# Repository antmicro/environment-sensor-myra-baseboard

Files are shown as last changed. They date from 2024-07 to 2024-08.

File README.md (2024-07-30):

# Environment Sensor MYRA SiP Baseboard
Copyright (c) 2024 [Antmicro](https://www.antmicro.com/)

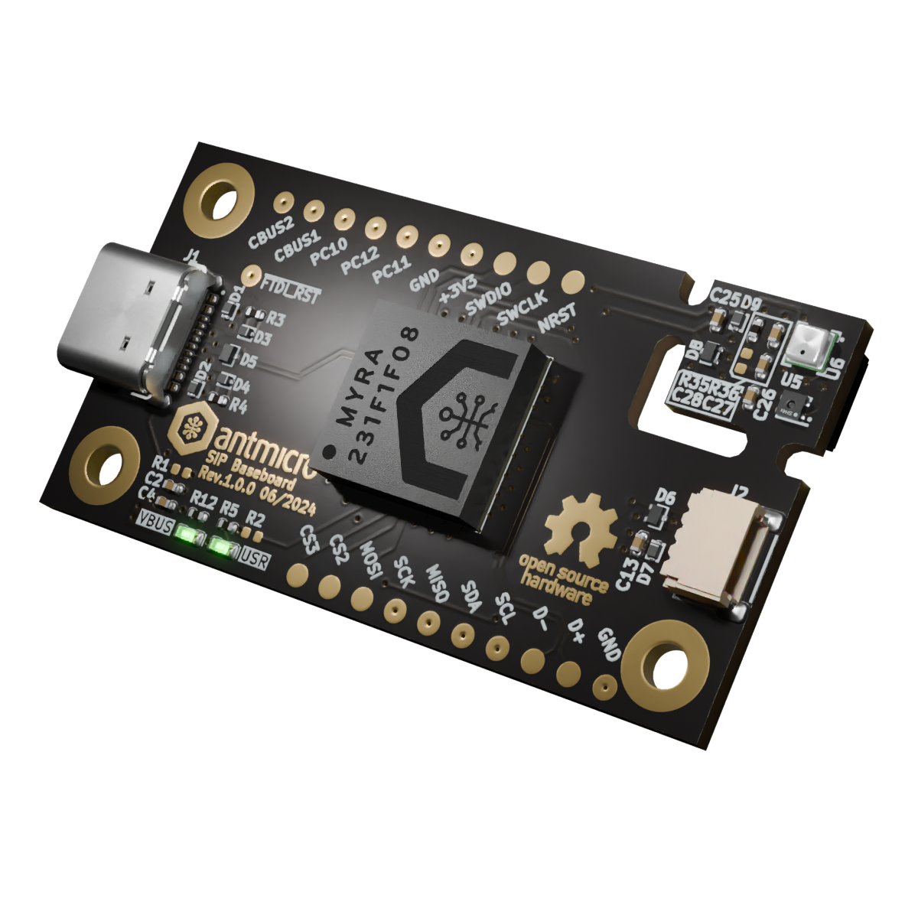
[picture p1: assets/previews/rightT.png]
Visualization


## Overview

This repository contains open hardware design files for Antmicro's Environment Sensor Board variant which includes the [MYRA SiP](https://github.com/antmicro/myra-sip) as well as temperature, pressure and humidity sensors.

The design files were prepared in KiCad 7.

## Key features

* Environment sensor SiP (with STM32G491REI6 MCU, 128kB FRAM, FTDI FT231XQ USB to UART converter)
* 50 mm x 26.5 mm PCB size
* USB-C Connector for data and power
* SHT45 temperature + humidity sensor:
	* typical relative humidity accuracy ±1% RH
	* operating relative humidity range 0-100% RH
	* typical temperature accuracy ±0.1°C
	* operating temperature range -40-125°C
* BME280 temperature + humidity + pressure sensor:
	* typical relative humidity accuracy ±3% RH
	* operating relative humidity range 10-100% RH
	* typical temperature accuracy ±1°C
	* operating temperature range -40-85°C
	* typical pressure accuracy ±1 hPa
	* operating pressure range 300-1100 hPa
* QWIIC Connectors
* RTC battery backup

## Repository structure

The main repository directory contains KiCad PCB project files, a LICENSE, and a README.
The remaining files are stored in the following directories:

* `doc` - contains board schematic
* `assets` - contains visual assets for showcasing this design on [Open Hardware Portal](https://openhardware.antmicro.com/boards/environment-sensor-sip-baseboard/?tab=features&view=top-ortho).

## Licensing
This project is published under the [Apache-2.0](https://github.com/antmicro/environment-sensor-sip-baseboard//blob/main/LICENSE) license.

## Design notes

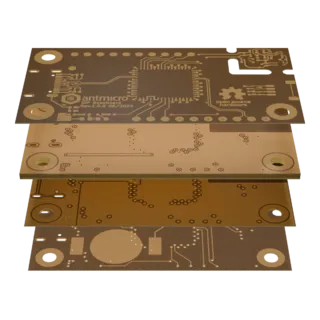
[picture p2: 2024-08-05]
assets/previews/layer1_thumbnail.webp

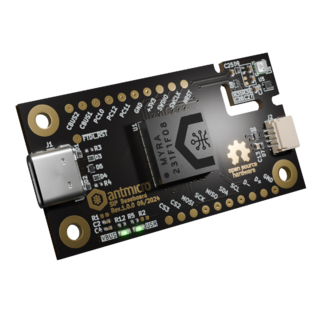
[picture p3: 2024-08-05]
assets/previews/leftT_thumbnail.png

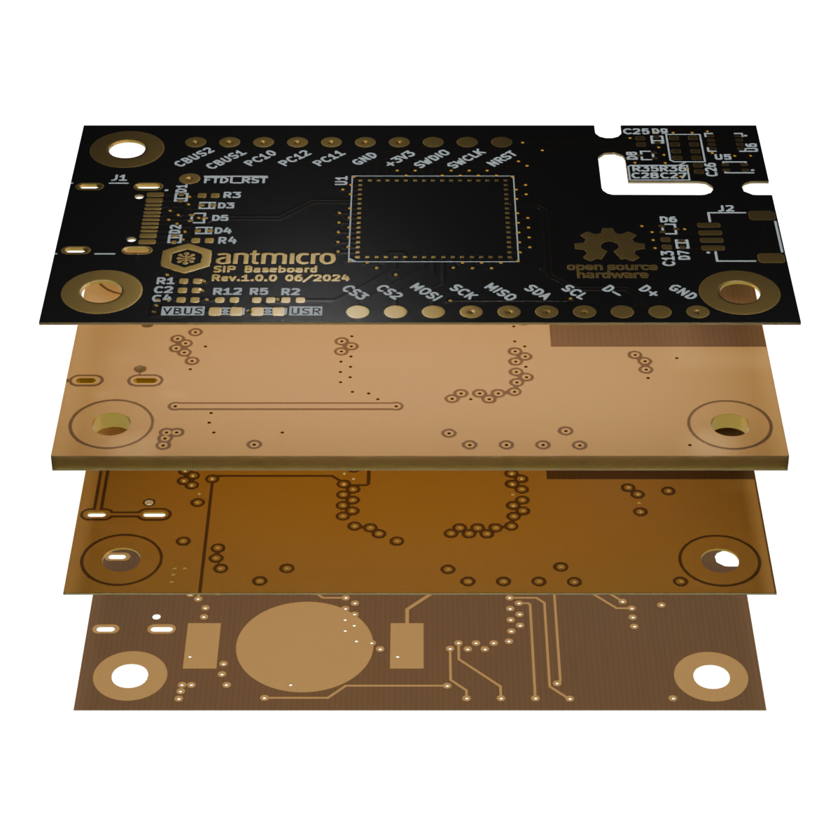
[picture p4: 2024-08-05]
assets/previews/stackup.png

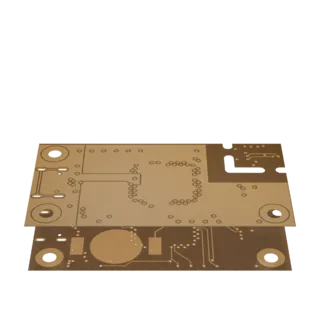
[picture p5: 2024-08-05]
assets/previews/layer3_thumbnail.webp

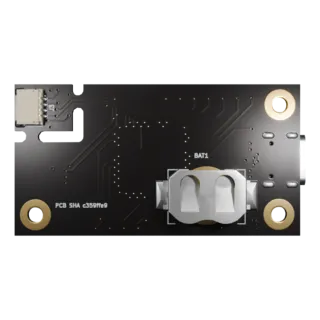
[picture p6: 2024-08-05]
assets/previews/orthoB_thumbnail.webp

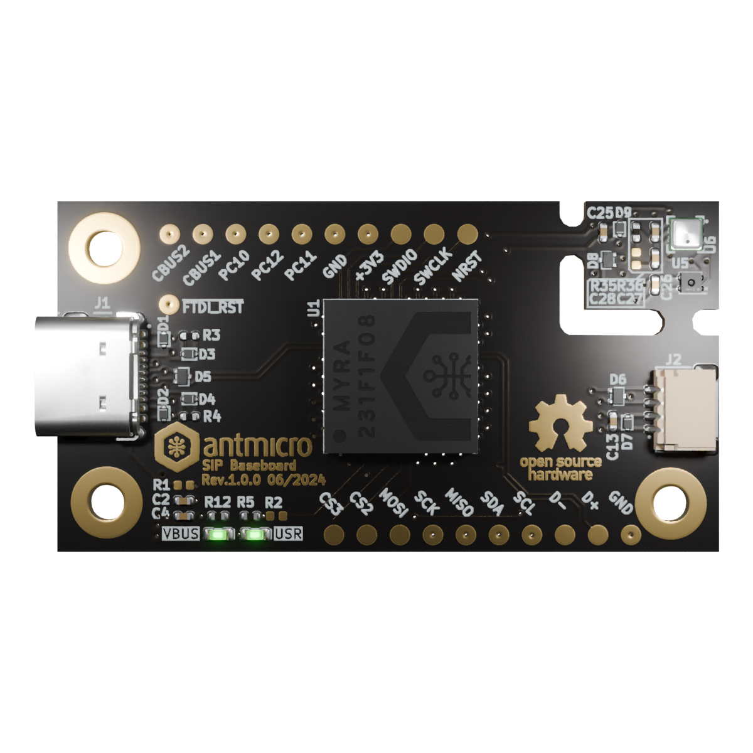
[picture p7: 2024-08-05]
assets/previews/orthoT.png

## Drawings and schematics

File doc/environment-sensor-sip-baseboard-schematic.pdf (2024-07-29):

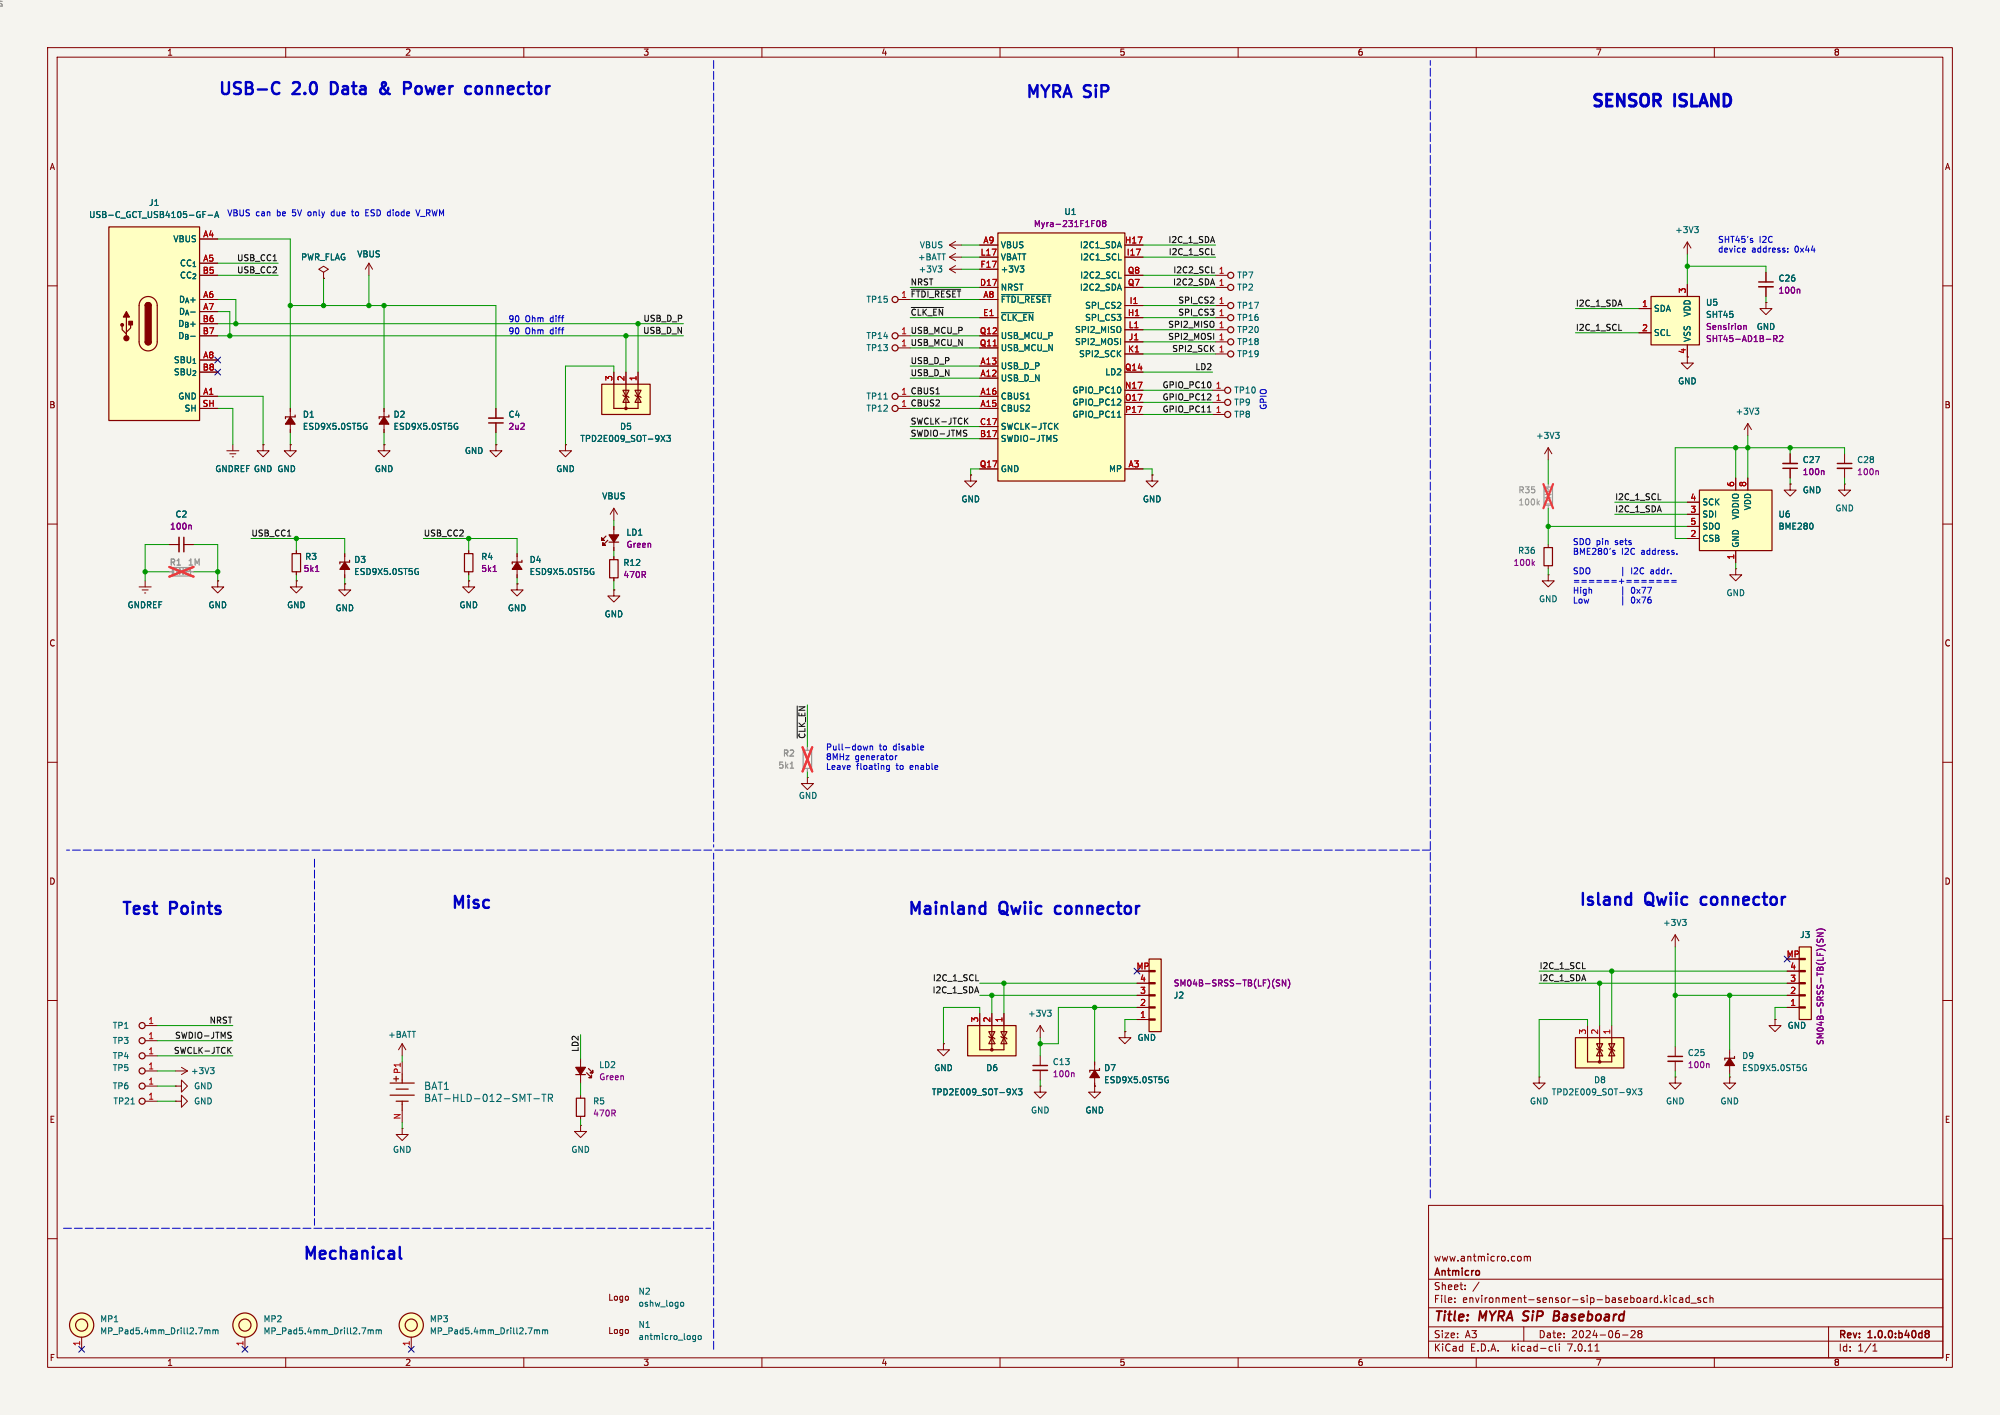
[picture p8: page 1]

VBUS can be 5V only due to ESD diode V_RWM

4 U5SHT45 Sensirion SHT45-AD1B-R2 USB_D_N A12 USB_D_P A13 CBUS2 A15 CBUS1 A16 MP A3 ~{FTDI_RESET} A8 VBUS A9 SWDIO-JTMS B17 SWCLK-JTCK C17 NRST D17 ~{CLK_EN} E1 +3V3 F17 SPI_CS3 H1

J3 SM04B-SRSS-TB(LF)(SN) 1

J2SM04B-SRSS-TB(LF)(SN) C13

File: environment-sensor-sip-baseboard.kicad_sch Sheet: / Antmicro www.antmicro.com

Id: 1/1 Title: MYRA SiP Baseboard

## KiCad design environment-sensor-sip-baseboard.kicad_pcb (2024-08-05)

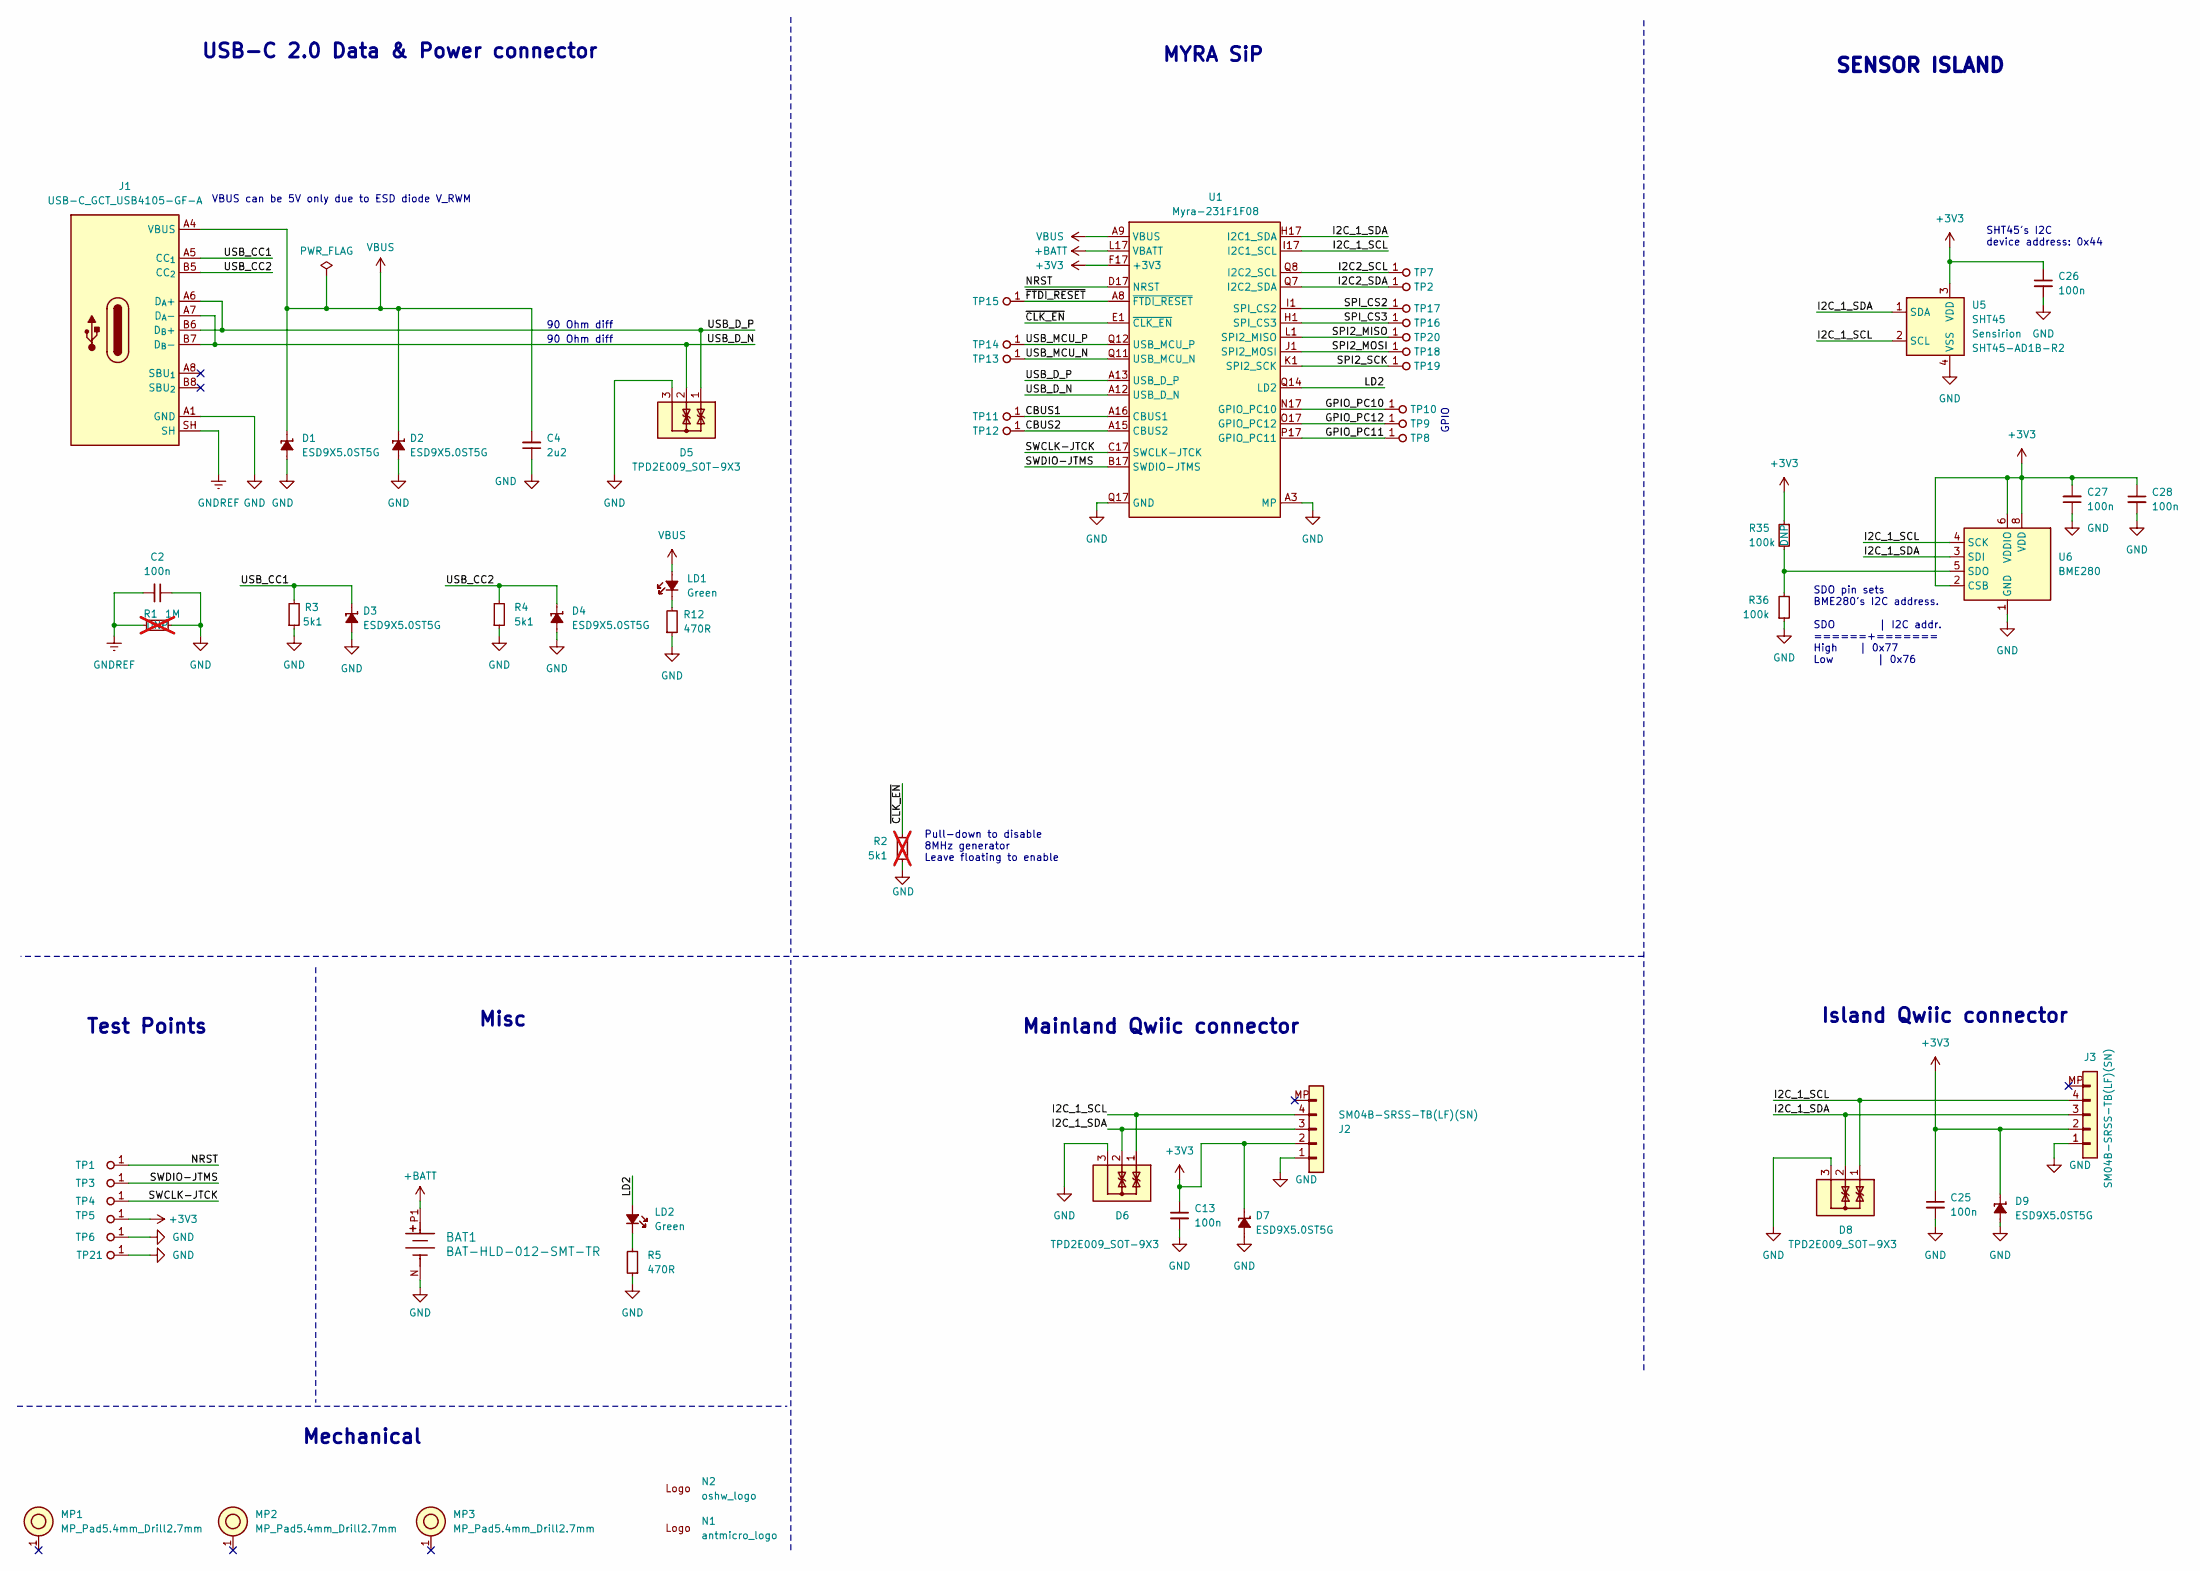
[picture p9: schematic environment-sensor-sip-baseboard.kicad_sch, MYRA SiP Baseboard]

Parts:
BAT1: BAT-HLD-012-SMT-TR; BAT_BAT-HLD-012-SMT-TR; MPN BAT-HLD-012-SMT-TR
C2, C13, C25, C26, C27, C28: C_100n_0402; C_0402_1005Metric; Voltage 50V; MPN GRM155R61H104KE14D
C4: C_2u2_0402; C_0402_1005Metric; MPN C1005X5R1A225K050BC
D1, D2, D3, D4, D7, D9: ESD9X5.0ST5G; SOD-923; MPN ESD9X5.0ST5G
D5, D6, D8: TPD2E009_SOT-9X3; SOT-723; MPN TPD2E009DRTR
J1: USB-C_GCT_USB4105-GF-A; USB-C_Receptacle_GCT_USB4105-GF-A; MPN USB4105-GF-A
J2, J3: JST_SH_1x4_SM04B-SRSS-TB-LF-SN; Conn_JST_SH_1x4_SM04B-SRSS-TB-LF-SN; MPN SM04B-SRSS-TB(LF)(SN)
LD1, LD2: LED_G_0603_KP-1608ZGC; LED_0603_1608Metric_G; MPN KP-1608ZGC
MP1, MP2, MP3: MP_Pad5.4mm_Drill2.7mm
N1: antmicro_logo; antmicro-logo_scaled_12mm
N2: oshw_logo; oshw-logo
R1: R_1M_0402; R_0402_1005Metric; Tolerance 1%; MPN CR0402-FX-1004GLF; not fitted
R2: R_5k1_0402; R_0402_1005Metric; Tolerance 1%; MPN CR0402-FX-5101GLF; not fitted
R3, R4: R_5k1_0402; R_0402_1005Metric; Tolerance 1%; MPN CR0402-FX-5101GLF
R5, R12: R_470R_0402; R_0402_1005Metric; Tolerance 1%; MPN CR0402-FX-4700GLF
R35, R36: R_100k_0402; R_0402_1005Metric; Tolerance 1%; MPN CR0402-FX-1003GLF
TP1, TP2, TP3, TP4, TP5, TP6, TP7, TP8, TP9, TP10, TP11, TP12, TP13, TP14, TP15, TP16, TP17, TP18, TP19, TP20, TP21: TP_1.5mm_SMD; TP_SMD_1.5mm
U1: Myra-231F1F08; LGA-64_11.4x11.4mm_Myra; MPN Myra-231F1F08
U5: SHT45; Sensirion_DFN-4-1.5x1.5x0.5mm_P0.8mm; MPN SHT45-AD1B-R2
U6: BME280; LGA-8_2.5x2.5mm_BME280; MPN BME280

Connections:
+3V3: C13.1, C25.1, C26.1, C27.2, C28.1, D7.1 (C), D9.1 (C), J2.2, J3.2, R35.1, TP5.1, U1.F17 (+3V3), U1.Q6 (+3V3), U5.3 (VDD), U6.2 (CSB), U6.6 (VDDIO), U6.8 (VDD)
+BATT: BAT1.P1, BAT1.P2, U1.L17 (VBATT)
/CBUS1: TP11.1, U1.A16 (CBUS1)
/CBUS2: TP12.1, U1.A15 (CBUS2)
/GPIO_PC10: TP10.1, U1.N17 (GPIO_PC10)
/GPIO_PC11: TP8.1, U1.P17 (GPIO_PC11)
/GPIO_PC12: TP9.1, U1.O17 (GPIO_PC12)
/I2C2_SCL: TP7.1, U1.Q8 (I2C2_SCL)
/I2C2_SDA: TP2.1, U1.Q7 (I2C2_SDA)
/I2C_1_SCL: D6.1, D8.1, J2.4, J3.4, U1.I17 (I2C1_SCL), U5.2 (SCL), U6.4 (SCK)
/I2C_1_SDA: D6.2, D8.2, J2.3, J3.3, U1.H17 (I2C1_SDA), U5.1 (SDA), U6.3 (SDI)
/LD2: LD2.2 (A), U1.Q14 (LD2)
/NRST: TP1.1, U1.D17 (NRST)
/SPI2_MISO: TP20.1, U1.L1 (SPI2_MISO)
/SPI2_MOSI: TP18.1, U1.J1 (SPI2_MOSI)
/SPI2_SCK: TP19.1, U1.K1 (SPI2_SCK)
/SPI_CS2: TP17.1, U1.I1 (SPI_CS2)
/SPI_CS3: TP16.1, U1.H1 (SPI_CS3)
/SWCLK-JTCK: TP4.1, U1.C17 (SWCLK-JTCK)
/SWDIO-JTMS: TP3.1, U1.B17 (SWDIO-JTMS)
/USB_CC1: D3.1 (C), J1.A5 (CC_{1}), R3.2
/USB_CC2: D4.1 (C), J1.B5 (CC_{2}), R4.2
/USB_D_N: D5.2, J1.A7 (D_{A}-), J1.B7 (D_{B}-), U1.A12 (USB_D_N)
/USB_D_P: D5.1, J1.A6 (D_{A}+), J1.B6 (D_{B}+), U1.A13 (USB_D_P)
/USB_MCU_N: TP13.1, U1.Q11 (USB_MCU_N)
/USB_MCU_P: TP14.1, U1.Q12 (USB_MCU_P)
/~CLK_EN: R2.2, U1.E1 (~CLK_EN)
/~FTDI_RESET: TP15.1, U1.A8 (~FTDI_RESET)
GND: BAT1.N, C2.1, C4.1, C13.2, C25.2, C26.2, C27.1, C28.2, D1.2 (A), D2.2 (A), D3.2 (A), D4.2 (A), D5.3, D6.3, D7.2 (A), D8.3, D9.2 (A), J1.A1 (GND), J1.A12 (GND), J1.B1 (GND), J1.B12 (GND), J2.1, J3.1, R1.2, R2.1, R3.1, R4.1, R5.1, R12.1, R36.1, TP6.1, TP21.1, U1.A1 (MP), U1.A2 (MP), U1.A3 (MP), U1.A4 (MP), U1.A5 (MP), U1.A6 (MP), U1.A7 (GND), U1.A11 (GND), U1.A14 (GND), U1.A17 (GND), U1.B1 (MP), U1.C1 (MP), U1.D1 (GND), U1.E17 (GND), U1.F1 (GND), U1.G1 (GND), U1.G17 (GND), U1.J17 (GND), U1.K17 (GND), U1.M1 (GND), U1.M17 (GND), U1.Q5 (GND), U1.Q9 (GND), U1.Q10 (GND), U1.Q13 (GND), U1.Q15 (GND), U1.Q16 (GND), U1.Q17 (GND), U5.4 (VSS), U6.1 (GND), U6.7 (GND)
GNDREF: C2.2, J1.SH, R1.1
unnamed: LD1.1 (C), R12.2
unnamed: LD2.1 (C), R5.2
unnamed: R35.2, R36.2, U6.5 (SDO)
VBUS: C4.2, D1.1 (C), D2.1 (C), J1.A4 (VBUS), J1.A9 (VBUS), J1.B4 (VBUS), J1.B9 (VBUS), LD1.2 (A), U1.A9 (VBUS), U1.A10 (VBUS)

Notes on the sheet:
Island Qwiic connector
MYRA SiP
90 Ohm diff
USB-C 2.0 Data & Power connector
SDO pin sets BME280's I2C address. SDO | I2C addr. ======+======= High | 0x77 Low | 0x76
VBUS can be 5V only due to ESD diode V_RWM
Pull-down to disable 8MHz generator Leave floating to enable
Misc
SENSOR ISLAND
SHT45's I2C device address: 0x44
Mainland Qwiic connector
Test Points
Mechanical
GPIO

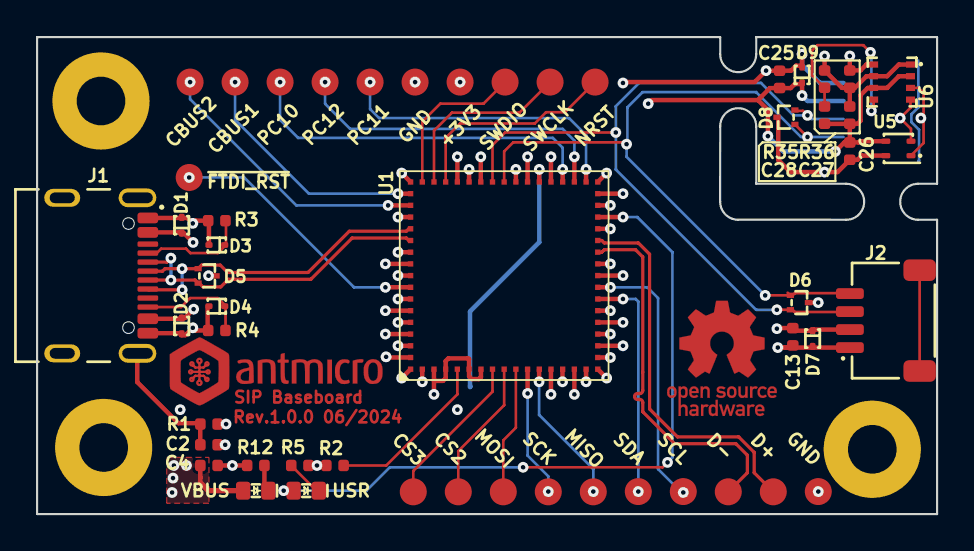
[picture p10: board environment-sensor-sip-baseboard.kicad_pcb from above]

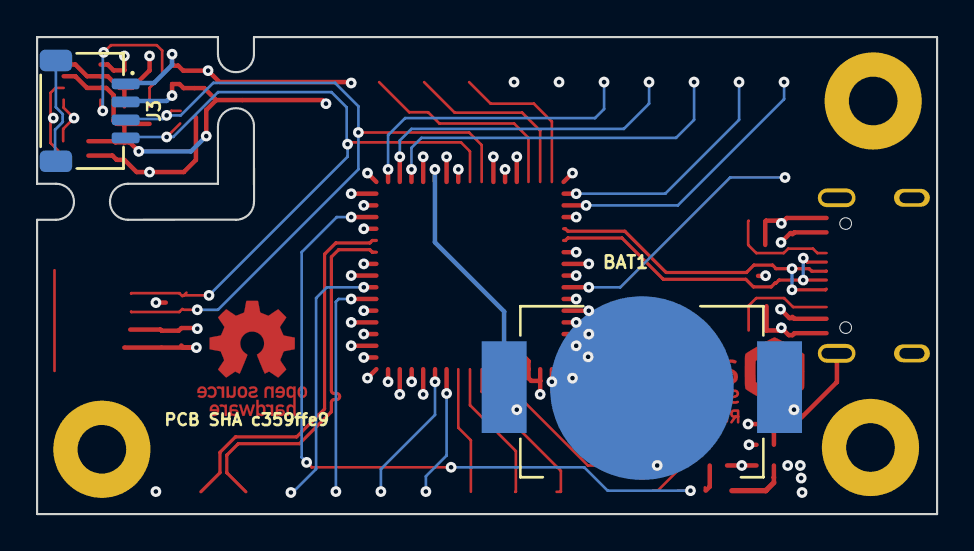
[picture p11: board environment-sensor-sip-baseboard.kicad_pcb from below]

Board: 4 copper layers, 50.0 x 26.5 mm, 59 parts (2 on the bottom side), 34 nets.

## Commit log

2024-06-27 [#61553] Initial commit. Create schematic
    [environment-sensor-sip-baseboard.kicad_sch]
2024-06-27 [#61553] Start PCB placement
    [environment-sensor-sip-baseboard.kicad_pcb]
2024-06-28 [#61553] Route PCB
    [environment-sensor-sip-baseboard.kicad_pcb, environment-sensor-sip-baseboard.kicad_sch]
2024-06-28 [#61553] Improve schematic readability
    [environment-sensor-sip-baseboard.kicad_pcb, environment-sensor-sip-baseboard.kicad_sch]
2024-06-28 [#61553] Update title block
    [environment-sensor-sip-baseboard.kicad_pcb, environment-sensor-sip-baseboard.kicad_sch]
2024-06-28 [#61553] Fix ERC
    [environment-sensor-sip-baseboard.kicad_sch]
2024-06-28 [#61553] Fix logo at PCB
    [environment-sensor-sip-baseboard.kicad_pcb, environment-sensor-sip-baseboard.kicad_sch]
2024-06-28 [#61553] Fill polygons
    [environment-sensor-sip-baseboard.kicad_pcb]
2024-07-12 [#62396] Update components
    [environment-sensor-sip-baseboard.kicad_pcb, environment-sensor-sip-baseboard.kicad_sch]
2024-07-12 [#62396] Update MYRA Description
    [environment-sensor-sip-baseboard.kicad_sch]
2024-07-12 [#62396] Fix ERC and DRC
    [environment-sensor-sip-baseboard.kicad_pcb, environment-sensor-sip-baseboard.kicad_sch]
2024-07-15 [#62396] Update title block
    [environment-sensor-sip-baseboard.kicad_pcb, environment-sensor-sip-baseboard.kicad_sch]
2024-07-16 [#62396] Update SiP
    [environment-sensor-sip-baseboard.kicad_pcb, environment-sensor-sip-baseboard.kicad_sch]
2024-07-22 [#62396] Update visualization
    [environment-sensor-sip-baseboard.kicad_pcb, environment-sensor-sip-baseboard.kicad_sch]
2024-07-29 [#62840] Prepare assets
    [stackup.csv]
2024-08-05 [#63457] Unify silkscreen orientation
    [environment-sensor-sip-baseboard.kicad_pcb]

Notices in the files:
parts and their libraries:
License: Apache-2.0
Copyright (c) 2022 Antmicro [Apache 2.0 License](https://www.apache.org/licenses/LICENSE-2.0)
